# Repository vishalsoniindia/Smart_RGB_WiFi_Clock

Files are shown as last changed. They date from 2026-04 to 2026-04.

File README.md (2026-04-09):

# 🚀 ESP32 Easy Upload Tool

A simple way to erase and upload code to your ESP32 using a batch file.  

---

## 📌 How It Works
The included **`esp32_upload.bat`** file will:
- Automatically erase the ESP32 flash memory
- Upload your program
- Allow quick reprogramming for multiple devices

---

## 🔧 Steps to Upload Code

1. Open the folder and **double-click** `esp32_upload.bat`.
2. If Windows shows *"Windows Protected your PC"*, click:
   - **More Info**
   - **Run Anyway**
3. From the COM port list, **select the list number [NOT COM NUMBER]** where your ESP32 is connected.
4. Press **Enter** to continue.
5. Wait until you see:  
   ✅ **"Flash Complete"** at the end.
6. Press **any key** if you want to program another device.

---

## ⚠️ Notes
- Make sure your ESP32 is properly connected via USB.
- Run the script with administrator privileges if you face permission issues.

---

✨ That’s it! Your ESP32 should now be running the uploaded code.

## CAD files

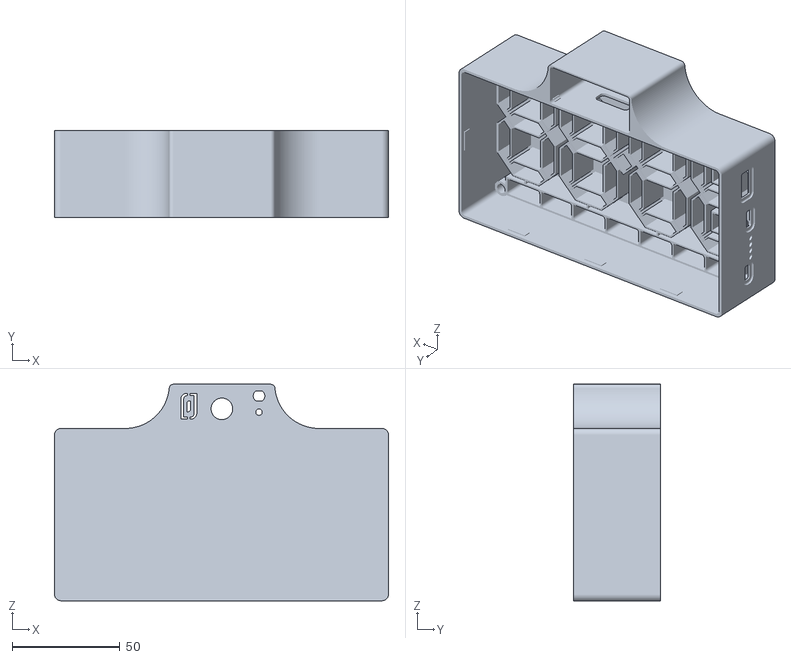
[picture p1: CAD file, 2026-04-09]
Mini_RGB_STL_Files/Main Case 1.stl
155.0 x 40.4 x 100.5

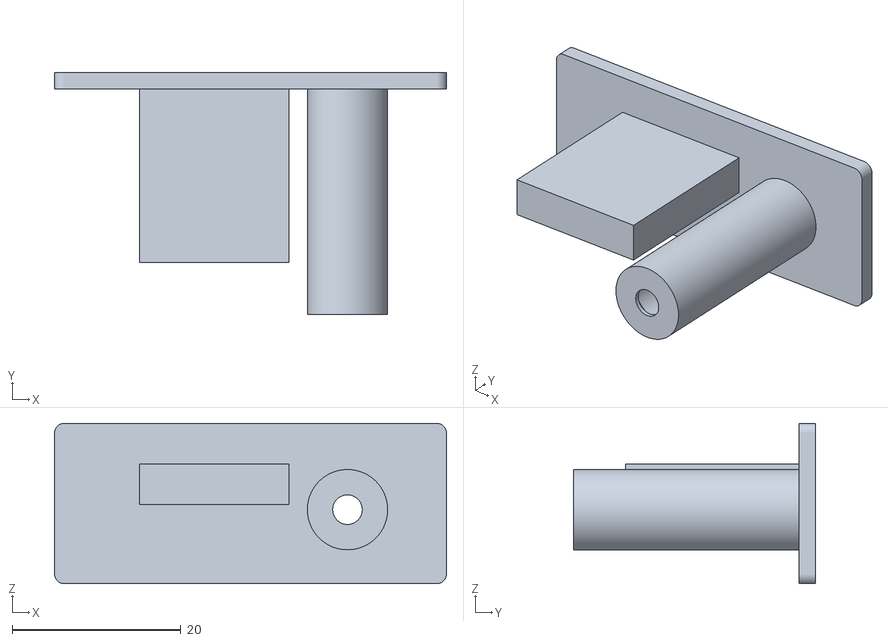
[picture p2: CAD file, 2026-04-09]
Mini_RGB_STL_Files/Sensor Cap 3.stl
46.4 x 28.7 x 19.0

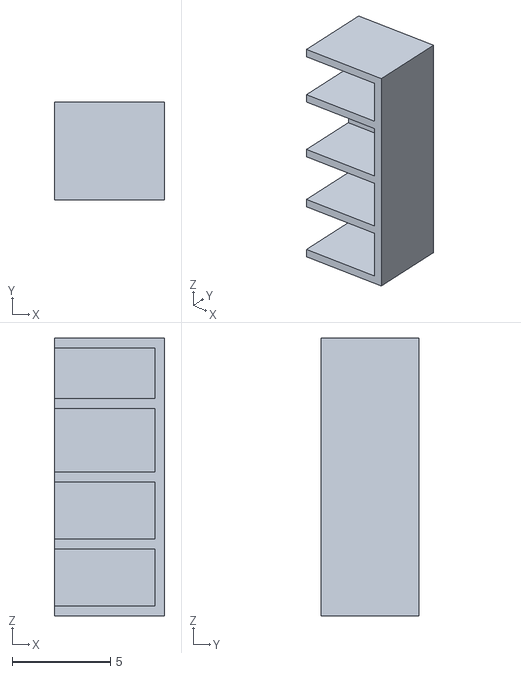
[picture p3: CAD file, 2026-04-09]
Mini_RGB_STL_Files/Fuel Guage sep 5.stl
5.60 x 5.00 x 14.1

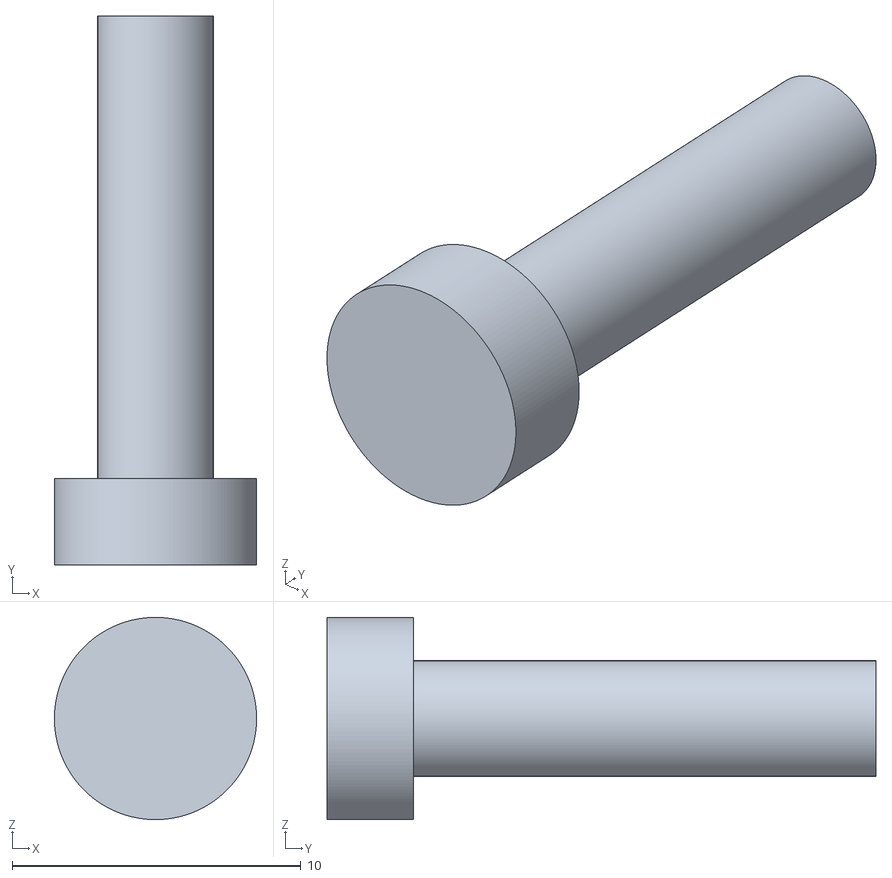
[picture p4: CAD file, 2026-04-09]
Mini_RGB_STL_Files/Key Lead 4.stl
7.00 x 19.0 x 7.00

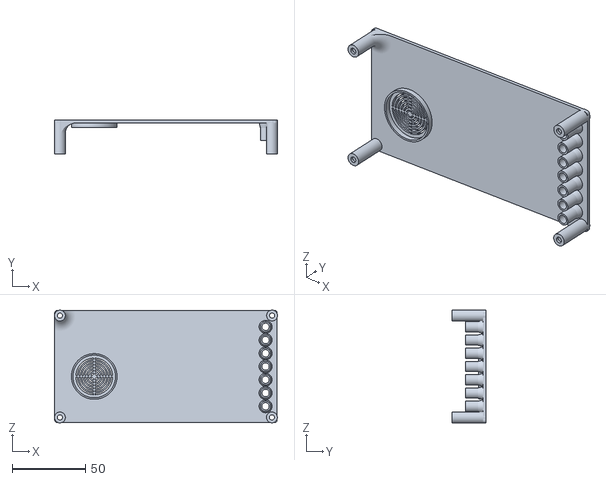
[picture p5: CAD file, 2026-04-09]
Mini_RGB_STL_Files/Back Cover 2.stl
151.8 x 23.0 x 76.8

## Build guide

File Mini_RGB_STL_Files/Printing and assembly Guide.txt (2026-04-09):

1)Threaded Brass Inserts
 M3x3mm  = 4 pc

2)Threaded Bolts
M3x8mm = 4 pc

3)Printing Guide
3.1 
We used Bambulab A1 printer Without AMS to print all the parts in PLA. 
We will keep front face of clock on build plate,
To Allow Light to Pass through PLA We are going to print 
first layer of MAIN CASE stl with LITHOPANE WHITE / WHITE PLA and put a pause, then change 
filament color to your choice for Remaining, we used Black for blocking Unnecessary lights .
all other parts can be Printed in your color of choice.

3.2
FUEL GUAGE stl part is required to stick on PCB where battery level led are placed making separation
for each led to avoid mixing of led light

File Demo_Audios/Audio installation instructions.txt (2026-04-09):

NOTE : Adding custom audio in jq6500 
You will need 6 Audios , Audio 1,2,3,4,5 corresponds to 5 Alarm and Audio 6 is for Theft Alarm. All are in mp3 format and all combined audio size should be below or up to 2000kb / 2 mb , most important is to enter audio name as 001 - 002 - 003 … where audio 1 is 001 and audio 2 is 002 and so on. Now you can Upload it in jQ6500 Module.

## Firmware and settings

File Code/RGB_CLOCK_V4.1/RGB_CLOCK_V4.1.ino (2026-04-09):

//parition scheme : Minimal SPIFFS

/*
* Auther : Vishal Soni (@electrodonut)
* ESP32 Board : V3.3.4
* FastLED : v3.10.3
* RTClib : v2.1.4
* DHT sensor Adafruit : v1.4.6
* JQ6500_Serial : (Link: https://github.com/sleemanj/JQ6500_Serial)
*/

/*++++++++++++++ Libraries ++++++++++++++++*/
#define FASTLED_ALLOW_INTERRUPTS 1
#define FASTLED_INTERRUPT_RETRY_COUNT 0

#include <Arduino.h>
#include <FastLED.h>
#include <Wire.h>
#include "RTClib.h"
#include <WiFi.h>
#include <ESPmDNS.h>
#include <WebServer.h>
#include <DNSServer.h>
#include <Preferences.h>
#include <ArduinoJson.h>
#include "DHT.h"
#include <JQ6500_Serial.h>
#include <Update.h>


#include "webpage.h"
#include "timezone.h"

/*++++++++++++++ Wifi ++++++++++++++++*/
String wifiSSID;
String wifiPassword;

WebServer server(80);
Preferences prefs;
Preferences wifiPrefs;
char mdnsHostname[32];

// Timezone handling
String tzString;  // Will hold POSIX timezone string

bool wifiConnected = false;
bool timeSynced = false;
unsigned long lastUpdateTime = 0;
bool apModeActive = false;
bool mdnsRunning = false;
bool serverRunning = false;


DNSServer dnsServer;
// const char* AP_PASSWORD = "12345678";  // ≥8 chars or set nullptr for open AP
const char *AP_PASSWORD = nullptr;
;  // ≥8 chars or set nullptr for open AP



/*++++++++++++++ Pin Declaration ++++++++++++++++*/
#define LED_PWR_RELAY 23
#define DATA_PIN 4
#define DHTPIN 18  // Digital pin connected to the DHT sensor
#define LDR 39
#define PIR 33
#define BUSY_AUDIO 25  //1 busy 0 free
#define UP_BUTTON 26
#define DOWN_BUTTON 27
#define OK_BUTTON 14
#define CONFIG_BUTTON 15

/*++++++++++++++ Display ++++++++++++++++*/
#define NUM_LEDS 73
CRGB leds[NUM_LEDS];         // Define the array of leds
int display_cycle_time = 3;  //seconds
unsigned long lastTimeDisplaySwitch = 0;
int Display_Value = 0;
#define MAX_DISPLAY_VALUES 3
String displayOnly;  // "all", "time", "temperature", "humidity"

/*++++++++++++++ Buttons ++++++++++++++++*/

const unsigned long debounceDelay = 50;  // ms

struct Button {
  uint8_t pin;
  bool lastStableState;
  bool lastReading;
  unsigned long lastDebounceTime;
  const char *name;
};

Button buttons[] = {
  { UP_BUTTON, LOW, LOW, 0, "UP" },
  { DOWN_BUTTON, LOW, LOW, 0, "DOWN" },
  { OK_BUTTON, LOW, LOW, 0, "OK" },
  { CONFIG_BUTTON, LOW, LOW, 0, "CONFIG" }
};

const int buttonCount = sizeof(buttons) / sizeof(buttons[0]);

/*++++++++++++++ Sound define ++++++++++++++++*/
#define Alarm1Sound 1
#define Alarm2Sound 2
#define Alarm3Sound 3
#define Alarm4Sound 4
#define Alarm5Sound 5
#define TheftAlarmSound 6
uint8_t alarm_volume = 30;

/*++++++++++++++ Alarm System ++++++++++++++++*/
// Alarm structure for 5 alarms
struct Alarm {
  bool enabled;
  int hour;
  int minute;
  int sound_num;
  unsigned long snooz_minute;
  int back_up_h;
  int back_up_m;
};

#define ALARM_COUNT 5

Alarm alarms[ALARM_COUNT] = {
  //true/false(enable/disale) , hour , minute, sound number, snooz minute, backup hour and backup minte?
  { false, 7, 0, Alarm1Sound, 1, 7, 0 },    // Alarm 1 - default 7:00 AM snooze 1 minute
  { false, 8, 0, Alarm2Sound, 10, 8, 0 },   // Alarm 2 - default 8:00 AM snooze 10 minute
  { false, 9, 0, Alarm3Sound, 5, 9, 0 },    // Alarm 3 - default 9:00 AM snooze 5 minute
  { false, 10, 0, Alarm4Sound, 0, 10, 0 },  // Alarm 4 - default 10:00 AM
  { false, 13, 0, Alarm5Sound, 0, 13, 0 }   // Alarm 5 - default 1:00 PM
};

bool alarm_is_active = 0;
bool is_snooz_pressed = 0;
int current_active_alarm = 0;

/*++++++++++++++ PIR ++++++++++++++++*/
bool first_time_on_before_pir = 0;
bool is_pir_on = 1;
bool turn_on_relay = 0;
int time_out_for_led_off = 1;  // 1 minute on
// int time_out_for_led_off = 1000 * 5 * 1;  // 1 minute on
unsigned long lastTimePirOn = 0;
JQ6500_Serial mp3(Serial2);

bool is_theft_on = 0;
int theftSoundTimeout;  // seconds
bool theftTimingEnabled;
struct TheftTime {
  uint8_t hour;
  uint8_t minute;
} theftStartTime, theftEndTime;
bool theftTimingInRange = 0;  //if in range turn it 1
bool Theft_active = 0;        //whill 1 if theft audio playing

/*++++++++++++++ LDR ++++++++++++++++*/
bool autoBrightness = 1;
int minRawValue = 4095;  // Expected in complete darkness
int maxRawValue = 1425;  // Expected in bright light
int minLedBrightness = 10;
int maxLedBrightness = 255;
int rawValue = 0;
int brightness;
// int lightLevel = 0;

/*++++++++++++++ DHT 11 ++++++++++++++++*/
bool is_temp_in_f = 0;
#define DHTTYPE DHT11
DHT dht(DHTPIN, DHTTYPE);
float humidity = 0;
float temperature = 0;

/*++++++++++++++ LEds ++++++++++++++++*/

// Define segments as reusable objects
CRGBSet hour_1(leds + 0, 14);   // First hour digit (LEDs 0-13, 14 LEDs total)
CRGBSet hour_2(leds + 14, 14);  // Second hour digit (LEDs 14-27, 14 LEDs)
CRGBSet sep_dot(leds + 28, 1);  // Separator dot (LED 28 only, 1 LED)
CRGBSet min_1(leds + 29, 14);   // First minute digit (LEDs 29-42, 14 LEDs)
CRGBSet min_2(leds + 43, 14);   // Second minute digit (LEDs 43-56, 14 LEDs)
CRGBSet sun(leds + 57, 2);
CRGBSet sat(leds + 59, 2);
CRGBSet fri(leds + 61, 2);
CRGBSet thu(leds + 63, 2);
CRGBSet wed(leds + 65, 2);
CRGBSet tue(leds + 67, 2);
CRGBSet mon(leds + 69, 2);
CRGBSet al(leds + 71, 1);
CRGBSet pm(leds + 72, 1);

unsigned long currentMillis = 0;
unsigned long lastPrintTime = 0;

// Animation variables
uint8_t gHue = 0;  // Global hue for rainbow

/*++++++++++++++ Time ++++++++++++++++*/
RTC_DS3231 rtc;
uint8_t hours = 2;
uint8_t minutes = 2;
uint8_t seconds = 0;

uint8_t date = 5;
uint8_t month = 10;
int year = 2001;
uint8_t weekday = 0;
uint8_t lastweekday = 255;

char daysOfWeek[7][12] = { "Sunday", "Monday", "Tuesday", "Wednesday", "Thursday", "Friday", "Saturday" };

bool enable_24_hour_mode = 0;  //make 1 to enable 24 hour mode
bool is_pm = 0;                //will 1 if pm
String timezone;
String timeMode;  // "12" or "24"

CRGB weekday_bg_color = CRGB::White;
CRGB weekday_selected_color = CRGB::Magenta;

/*++++++++++++++ Colors Solid ++++++++++++++++*/

String colorMode;
String solidColor;
String effect;

enum color_mode {
  SOLID,
  EFFECT
};

enum color_mode Color_Mode = EFFECT;

enum color_of_time {
  RED,  // Basic colors
  GREEN,
  BLUE,
  WHITE,
  BLACK,   // Off
  YELLOW,  // Secondary colors
  CYAN,
  MAGENTA,
  ORANGE,  // Tertiary colors
  PURPLE,
  PINK,
  TEAL,
  LIME,
  AMBER,  // Warm colors
  GOLD,
  CORAL,
  LAVENDER,  // Pastels
  SKYBLUE,
  FORESTGREEN,
  MAROON,
  OLIVE,
  NAVY,
  INDIGO
};

enum color_of_time current_color = MAROON;

/*++++++++++++++ effects of time ++++++++++++++++*/

enum effect_of_time {
  RAINBOW_1,  // slow rainbow
  RAINBOW_2,
  RAINBOW_3
};

enum effect_of_time current_effect = RAINBOW_2;

/* ---- Theme ---- */
bool lightTheme;

// ===================== declaration =====================
long getUtcOffsetSeconds(const String &tz);

// ===================== Setup() =====================

void setup() {
  Serial.begin(115200);
  Serial.println("========================== Beginning of Code ============================");
  loadPreferences();
  loadWiFiCredentials();

  WiFi.begin(wifiSSID.c_str(), wifiPassword.c_str());
  update_hostname();

  // FastLED.addLeds<WS2812B, DATA_PIN, GRB>(leds, NUM_LEDS);  // GRB ordering is typical
  FastLED.addLeds<WS2812B, DATA_PIN, GRB>(leds, NUM_LEDS).setCorrection(TypicalLEDStrip);

  Wire.begin();  // Initialize I2C with default pins (21-SDA, 22-SCL)

  // Initialize RTC
  if (!rtc.begin()) {
    Serial.println("Couldn't find RTC!");
    Serial.flush();
    while (1) delay(10);
  }

  dht.begin();

  Serial2.begin(9600, SERIAL_8N1, 16, 17);
  mp3.reset();
  mp3.setVolume(alarm_volume);
  mp3.setLoopMode(MP3_LOOP_NONE);

  pinMode(BUSY_AUDIO, INPUT);
  pinMode(LDR, INPUT);
  pinMode(PIR, INPUT);
  pinMode(LED_PWR_RELAY, OUTPUT);
  digitalWrite(LED_PWR_RELAY, HIGH);
  turn_on_relay = 1;

  // server_start();

  // test alarm
  // DateTime now = rtc.now();
  // hours = now.hour();
  // minutes = now.minute();
  // seconds = now.second();
  // set_alarm(1, true, hours, minutes + 1, Alarm1Sound, 1);  //alarm number(1-5), enable(true-false), hour, minute, sound, snooze minute
}

// ===================== Loop() =====================

void loop() {
  server.handleClient();
  if (apModeActive) {
    dnsServer.processNextRequest();
  }
  currentMillis = millis();
  button_handler();
  PIR_handle();
  updateTime();
  handle_alarm();
  PrintDebug();
  WifiHandle();
  UpdateDHT();

  // EVERY_N_MILLISECONDS(33) {  // ~30 FPS

  if (turn_on_relay) {
    autoBrightness_handle();
    // FastLED.setBrightness(255);
    display_weekday();
    Alarm_led_handle();

    if ((currentMillis - lastTimeDisplaySwitch > (display_cycle_time * 1000)) && displayOnly == "all") {
      lastTimeDisplaySwitch = currentMillis;
      Display_Value = (Display_Value + 1) % MAX_DISPLAY_VALUES;
      clearAllSegments_NoWeek();
    }

    if (Color_Mode == SOLID) {
      if (Display_Value == 0) {
        displayTime((uint8_t)current_color, Color_Mode);
      } else if (Display_Value == 1) {
        displayHumidity((uint8_t)current_color, Color_Mode);
      } else if (Display_Value == 2) {
        displayTemperature((uint8_t)current_color, Color_Mode);
      }
    } else {
      if (Display_Value == 0) {
        displayTime((uint8_t)current_effect, Color_Mode);
      } else if (Display_Value == 1) {
        displayHumidity((uint8_t)current_effect, Color_Mode);
      } else if (Display_Value == 2) {
        displayTemperature((uint8_t)current_effect, Color_Mode);
      }
      // Update animation based on effect speed
      if (current_effect == RAINBOW_1) {
        gHue++;            // Update hue for animation
        FastLED.delay(5);  // Fast animation
      } else if (current_effect == RAINBOW_2) {
        gHue++;             // Update hue for animation
        FastLED.delay(15);  // Medium animation
      } else if (current_effect == RAINBOW_3) {
        gHue++;             // Update hue for animation
        FastLED.delay(30);  // Slow animation
      }
    }

    FastLED.show();
  }
  // }
}

// ===================== Button Handler =====================
void button_handler() {
  for (int i = 0; i < buttonCount; i++) {
    bool reading = digitalRead(buttons[i].pin);

    // If state changed, reset debounce timer
    if (reading != buttons[i].lastReading) {
      buttons[i].lastDebounceTime = millis();
    }

    // If debounce time passed, accept new state
    if ((millis() - buttons[i].lastDebounceTime) > debounceDelay) {
      if (reading != buttons[i].lastStableState) {
        buttons[i].lastStableState = reading;

        // Print only on press (HIGH)
        if (reading == HIGH) {
          Serial.print(buttons[i].name);
          Serial.println(" button pressed");

          switch (buttons[i].pin) {
            case UP_BUTTON:
              break;
            case DOWN_BUTTON:
              break;
            case OK_BUTTON:
              if (alarm_is_active) {
                is_snooz_pressed = 1;
              }
              break;
            case CONFIG_BUTTON:
              startAPMode();
              break;
            default:
              break;
          }
        }
      }
    }

    buttons[i].lastReading = reading;
  }
}

// ===================== Audio =====================
void stop_audio() {
  mp3.reset();
  mp3.setVolume(alarm_volume);
}

// ===================== Set Alarm =====================

void handle_alarm() {
  for (int i = 0; i < ALARM_COUNT; i++) {
    if (alarms[i].enabled) {
      if (alarms[i].hour == hours && alarms[i].minute == minutes && seconds == 0) {

        current_active_alarm = i;
        Serial.println("============================================");
        Serial.print("Alarm Started: ");
        Serial.println(current_active_alarm + 1);
        Serial.println("============================================");

        if (alarms[i].hour == alarms[i].back_up_h && alarms[i].minute == alarms[i].back_up_m) {
          reset_alarm_to_defult();  //this well remove any snooze times
        }

        if (is_pir_on && !turn_on_relay) {
          TurnOnDisplay();
          turn_on_relay = 1;
        }
        if (digitalRead(BUSY_AUDIO)) {
          stop_audio();
        }
        mp3.setLoopMode(MP3_LOOP_ONE_STOP);
        mp3.playFileByIndexNumber(alarms[i].sound_num);
        alarm_is_active = 1;
        Theft_active = 0;  //stop theft if alarm start
      }
    }
  }

  if (alarm_is_active) {

    //no snooze pressed & completed
    if (!digitalRead(BUSY_AUDIO)) {
      Serial.println("============================================");
      Serial.print("Alarm Stopped: ");
      Serial.println(current_active_alarm + 1);
      Serial.println("============================================");
      alarm_is_active = 0;
      if (is_pir_on && turn_on_relay) {
        turn_on_relay = 0;
        TurnOffDisplay();
      }
      reset_alarm_to_defult();
    }

    //snooze pressed
    if (is_snooz_pressed) {
      Serial.println("============================================");
      Serial.print("Alarm Snooze: ");
      Serial.println(current_active_alarm + 1);
      Serial.println("============================================");
      stop_audio();
      is_snooz_pressed = 0;
      alarm_is_active = 0;
      addMinutes(alarms[current_active_alarm].hour, alarms[current_active_alarm].minute, alarms[current_active_alarm].snooz_minute);
      if (is_pir_on) {
        turn_on_relay = 0;
        TurnOffDisplay();
      }
    }
  }
}

void reset_alarm_to_defult() {
  for (int i = 0; i < 5; i++) {
    alarms[i].hour = alarms[i].back_up_h;
    alarms[i].minute = alarms[i].back_up_m;
  }
}

void addMinutes(int &hours, int &minutes, int minutesToAdd) {
  // Convert everything to total minutes
  int totalMinutes = hours * 60 + minutes + minutesToAdd;

  // Handle rollover (24-hour format)
  totalMinutes = totalMinutes % (24 * 60);

  // Convert back to hours and minutes
  hours = totalMinutes / 60;
  minutes = totalMinutes % 60;
}

void set_alarm(uint8_t alarm_num, bool alarm_state, uint8_t alarm_hour, uint8_t alarm_minute, uint8_t alarm_sound, int snooze_minute) {  //alarm number(1-5), enable(true-false), hour, minute, sound, snooze minute
  alarm_num = alarm_num - 1;                                                                                                             //convert to array
  alarms[alarm_num].enabled = alarm_state;
  alarms[alarm_num].hour = alarm_hour;
  alarms[alarm_num].minute = alarm_minute;
  alarms[alarm_num].sound_num = alarm_sound;
  alarms[alarm_num].snooz_minute = snooze_minute;
  alarms[alarm_num].back_up_h = alarm_hour;
  alarms[alarm_num].back_up_m = alarm_minute;
}

void toggle_alarm(uint8_t alarm_num, bool alarm_state) {
  alarm_num = alarm_num - 1;  //convert to array
  alarms[alarm_num].enabled = alarm_state;
}

// ===================== Turn On Display =====================

void TurnOnDisplay() {
  digitalWrite(LED_PWR_RELAY, HIGH);
}

void TurnOffDisplay() {
  digitalWrite(LED_PWR_RELAY, LOW);
}

// ===================== PIR =====================

void PIR_handle() {
  if (theftTimingEnabled) {
    theftTimingInRange = is_time_between(hours, minutes, theftStartTime.hour, theftStartTime.minute, theftEndTime.hour, theftEndTime.minute);
  } else {
    theftTimingInRange = 1;
  }

  if (Theft_active && !digitalRead(BUSY_AUDIO)) {
    mp3.setLoopMode(MP3_LOOP_ONE);
    mp3.playFileByIndexNumber(TheftAlarmSound);
  }

  if (is_pir_on) {
    //first time on
    if (turn_on_relay && (currentMillis - lastTimePirOn) > (10 * 1000) && !Theft_active && !first_time_on_before_pir) {
      turn_on_relay = 0;
      TurnOffDisplay();
      first_time_on_before_pir = 1;
    }

    if (turn_on_relay && (currentMillis - lastTimePirOn) > (time_out_for_led_off * 1000 * 60) && !Theft_active) {
      if (is_theft_on && !alarm_is_active) {
        stop_audio();
      }
      turn_on_relay = 0;
      TurnOffDisplay();
    }

    //for theft
    if ((currentMillis - lastTimePirOn) > (theftSoundTimeout * 1000) && is_theft_on && Theft_active && !alarm_is_active) {
      stop_audio();
      Theft_active = 0;
      turn_on_relay = 0;
      TurnOffDisplay();
    }

    if (digitalRead(PIR) == HIGH && !turn_on_relay && !alarm_is_active) {
      if (is_theft_on && !alarm_is_active && theftTimingInRange) {
        Theft_active = 1;
      }

      TurnOnDisplay();
      turn_on_relay = 1;
      lastTimePirOn = currentMillis;
    }

    // if (turn_on_relay && is_theft_on && !digitalRead(BUSY_AUDIO)) {
    //   mp3.playFileByIndexNumber(TheftAlarmSound);
    // }

  } else {
    TurnOnDisplay();
    turn_on_relay = 1;

    if (digitalRead(PIR) == HIGH && !alarm_is_active && is_theft_on && theftTimingInRange) {
      Theft_active = 1;
      lastTimePirOn = currentMillis;
    }

    if ((currentMillis - lastTimePirOn) > (theftSoundTimeout * 1000) && is_theft_on && Theft_active && !alarm_is_active) {
      stop_audio();
      Theft_active = 0;
    }
  }
}

void checkRangeOfTheftTime() {
  bool theftTimingEnabled;
  struct TheftTime {
    uint8_t hour;
    uint8_t minute;
  } theftStartTime, theftEndTime;
  bool theftTimingInRange = 0;  //if in range turn it 1

  if (theftTimingEnabled) {
    theftTimingInRange = 0;
    if (theftStartTime.hour) {
    }
  } else {
    theftTimingInRange = 1;
  }
}

// Function to check if current time is between start and end times
int is_time_between(int current_hour, int current_minute,
                    int start_hour, int start_minute,
                    int end_hour, int end_minute) {

  // Convert all times to minutes since midnight
  int current_total = current_hour * 60 + current_minute;
  int start_total = start_hour * 60 + start_minute;
  int end_total = end_hour * 60 + end_minute;

  if (start_total <= end_total) {
    // Normal same-day case
    if (start_total <= current_total && current_total <= end_total) {
      return 1;
    }
  } else {
    // Next-day case (end time is on next day)
    if (current_total >= start_total || current_total <= end_total) {
      return 1;
    }
  }
  return 0;
}

// ===================== LDR =====================

float smoothedLightLevel = 0.0;  // Initial value
const float alpha = 0.2;         // Smoothing factor (0.1-0.3). Lower = smoother, slower response.
unsigned long lastLDRRead = 0;
const unsigned long LDR_READ_INTERVAL = 100;  // Read every 100ms

// Modify autoBrightness() function
void autoBrightness_handle() {
  if (autoBrightness) {
    if (currentMillis - lastLDRRead >= LDR_READ_INTERVAL) {
      lastLDRRead = currentMillis;
      rawValue = analogRead(LDR);

      // The LDR reading is INVERTED: high value = dark, low value = bright.
      int newLightLevel = map(rawValue, minRawValue, maxRawValue, minLedBrightness, maxLedBrightness);
      newLightLevel = constrain(newLightLevel, minLedBrightness, maxLedBrightness);

      // Apply Exponential Moving Average Filter
      smoothedLightLevel = (alpha * newLightLevel) + ((1 - alpha) * smoothedLightLevel);

      // Apply the smoothed brightness
      FastLED.setBrightness((int)smoothedLightLevel);
    }
  } else {
    int newLightLevel = map(brightness, 0, 100, minLedBrightness, maxLedBrightness);
    FastLED.setBrightness(newLightLevel);
  }
}


// ===================== Update DHT =====================
void UpdateDHT() {
  humidity = dht.readHumidity();

  if (!is_temp_in_f) {
    // Read temperature as Celsius (the default)
    temperature = dht.readTemperature();
  } else {
    // Read temperature as Fahrenheit (isFahrenheit = true)
    temperature = dht.readTemperature(true);
  }

  if (isnan(humidity) || isnan(temperature)) {
    Serial.println(F("Failed to read from DHT sensor!"));
    return;
  }
}

// ===================== DIGIT PATTERNS =====================
// Each digit pattern controls 14 LEDs (like two 7-segment digits)
// 1 = LED ON, 0 = LED OFF
const bool digitPattern[13][14] = {
  // Digit 0
  { 1, 1, 1, 1, 1, 1, 0, 0, 1, 1, 1, 1, 1, 1 },
  // Digit 1
  { 0, 0, 0, 0, 1, 1, 0, 0, 0, 0, 0, 0, 1, 1 },
  // Digit 2
  { 0, 0, 1, 1, 1, 1, 1, 1, 1, 1, 1, 1, 0, 0 },
  // Digit 3
  { 0, 0, 1, 1, 1, 1, 1, 1, 0, 0, 1, 1, 1, 1 },
  // Digit 4
  { 1, 1, 0, 0, 1, 1, 1, 1, 0, 0, 0, 0, 1, 1 },
  // Digit 5
  { 1, 1, 1, 1, 0, 0, 1, 1, 0, 0, 1, 1, 1, 1 },
  // Digit 6
  { 1, 1, 1, 1, 0, 0, 1, 1, 1, 1, 1, 1, 1, 1 },
  // Digit 7
  { 0, 0, 1, 1, 1, 1, 0, 0, 0, 0, 0, 0, 1, 1 },
  // Digit 8
  { 1, 1, 1, 1, 1, 1, 1, 1, 1, 1, 1, 1, 1, 1 },
  // Digit 9
  { 1, 1, 1, 1, 1, 1, 1, 1, 0, 0, 1, 1, 1, 1 },
  // Digit 10 /H
  { 1, 1, 0, 0, 1, 1, 1, 1, 1, 1, 0, 0, 1, 1 },
  // Digit 11 /F
  { 1, 1, 1, 1, 0, 0, 1, 1, 1, 1, 0, 0, 0, 0 },
  // Digit 12 /C
  { 1, 1, 1, 1, 0, 0, 0, 0, 1, 1, 1, 1, 0, 0 },
};

// ===================== CORE FUNCTIONS =====================
void Alarm_led_handle() {
  al[0] = CRGB::Black;
  for (int i = 0; i < 5; i++) {
    if (alarms[i].enabled) {
      al[0] = CRGB::Red;
    }
  }
}

void display_weekday() {
  if (lastweekday != weekday) {
    // Serial.print("last week:");
    // Serial.print(lastweekday);
    // Serial.print(" ");
    // Serial.print("week:");
    // Serial.println(weekday);
    lastweekday = weekday;
    highlightDay(weekday_bg_color, weekday_selected_color, weekday);
  }
}
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

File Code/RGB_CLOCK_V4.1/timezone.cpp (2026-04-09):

// timezones.cpp
#include "timezone.h"

// Define the actual array here
const TimezoneEntry timezoneDatabase[] PROGMEM = {
    {"Africa/Abidjan", "GMT0"},
    {"Africa/Accra", "GMT0"},
    {"Africa/Addis_Ababa", "EAT-3"},
    {"Africa/Algiers", "CET-1"},
    {"Africa/Asmara", "EAT-3"},
    {"Africa/Bamako", "GMT0"},
    {"Africa/Bangui", "WAT-1"},
    {"Africa/Banjul", "GMT0"},
    {"Africa/Bissau", "GMT0"},
    {"Africa/Blantyre", "CAT-2"},
    {"Africa/Brazzaville", "WAT-1"},
    {"Africa/Bujumbura", "CAT-2"},
    {"Africa/Cairo", "EET-2EEST,M4.5.5/0,M10.5.4/24"},
    {"Africa/Casablanca", "<+01>-1"},
    {"Africa/Ceuta", "CET-1CEST,M3.5.0,M10.5.0/3"},
    {"Africa/Conakry", "GMT0"},
    {"Africa/Dakar", "GMT0"},
    {"Africa/Dar_es_Salaam", "EAT-3"},
    {"Africa/Djibouti", "EAT-3"},
    {"Africa/Douala", "WAT-1"},
    {"Africa/El_Aaiun", "<+01>-1"},
    {"Africa/Freetown", "GMT0"},
    {"Africa/Gaborone", "CAT-2"},
    {"Africa/Harare", "CAT-2"},
    {"Africa/Johannesburg", "SAST-2"},
    {"Africa/Juba", "CAT-2"},
    {"Africa/Kampala", "EAT-3"},
    {"Africa/Khartoum", "CAT-2"},
    {"Africa/Kigali", "CAT-2"},
    {"Africa/Kinshasa", "WAT-1"},
    {"Africa/Lagos", "WAT-1"},
    {"Africa/Libreville", "WAT-1"},
    {"Africa/Lome", "GMT0"},
    {"Africa/Luanda", "WAT-1"},
    {"Africa/Lubumbashi", "CAT-2"},
    {"Africa/Lusaka", "CAT-2"},
    {"Africa/Malabo", "WAT-1"},
    {"Africa/Maputo", "CAT-2"},
    {"Africa/Maseru", "SAST-2"},
    {"Africa/Mbabane", "SAST-2"},
    {"Africa/Mogadishu", "EAT-3"},
    {"Africa/Monrovia", "GMT0"},
    {"Africa/Nairobi", "EAT-3"},
    {"Africa/Ndjamena", "WAT-1"},
    {"Africa/Niamey", "WAT-1"},
    {"Africa/Nouakchott", "GMT0"},
    {"Africa/Ouagadougou", "GMT0"},
    {"Africa/Porto-Novo", "WAT-1"},
    {"Africa/Sao_Tome", "GMT0"},
    {"Africa/Tripoli", "EET-2"},
    {"Africa/Tunis", "CET-1"},
    {"Africa/Windhoek", "CAT-2"},
    {"America/Adak", "HST10HDT,M3.2.0,M11.1.0"},
    {"America/Anchorage", "AKST9AKDT,M3.2.0,M11.1.0"},
    {"America/Anguilla", "AST4"},
    {"America/Antigua", "AST4"},
    {"America/Araguaina", "<-03>3"},
    {"America/Argentina/Buenos_Aires", "<-03>3"},
    {"America/Argentina/Catamarca", "<-03>3"},
    {"America/Argentina/Cordoba", "<-03>3"},
    {"America/Argentina/Jujuy", "<-03>3"},
    {"America/Argentina/La_Rioja", "<-03>3"},
    {"America/Argentina/Mendoza", "<-03>3"},
    {"America/Argentina/Rio_Gallegos", "<-03>3"},
    {"America/Argentina/Salta", "<-03>3"},
    {"America/Argentina/San_Juan", "<-03>3"},
    {"America/Argentina/San_Luis", "<-03>3"},
    {"America/Argentina/Tucuman", "<-03>3"},
    {"America/Argentina/Ushuaia", "<-03>3"},
    {"America/Aruba", "AST4"},
    {"America/Asuncion", "<-03>3"},
    {"America/Atikokan", "EST5"},
    {"America/Bahia", "<-03>3"},
    {"America/Bahia_Banderas", "CST6"},
    {"America/Barbados", "AST4"},
    {"America/Belem", "<-03>3"},
    {"America/Belize", "CST6"},
    {"America/Blanc-Sablon", "AST4"},
    {"America/Boa_Vista", "<-04>4"},
    {"America/Bogota", "<-05>5"},
    {"America/Boise", "MST7MDT,M3.2.0,M11.1.0"},
    {"America/Cambridge_Bay", "MST7MDT,M3.2.0,M11.1.0"},
    {"America/Campo_Grande", "<-04>4"},
    {"America/Cancun", "EST5"},
    {"America/Caracas", "<-04>4"},
    {"America/Cayenne", "<-03>3"},
    {"America/Cayman", "EST5"},
    {"America/Chicago", "CST6CDT,M3.2.0,M11.1.0"},
    {"America/Chihuahua", "CST6"},
    {"America/Costa_Rica", "CST6"},
    {"America/Creston", "MST7"},
    {"America/Cuiaba", "<-04>4"},
    {"America/Curacao", "AST4"},
    {"America/Danmarkshavn", "GMT0"},
    {"America/Dawson", "MST7"},
    {"America/Dawson_Creek", "MST7"},
    {"America/Denver", "MST7MDT,M3.2.0,M11.1.0"},
    {"America/Detroit", "EST5EDT,M3.2.0,M11.1.0"},
    {"America/Dominica", "AST4"},
    {"America/Edmonton", "MST7MDT,M3.2.0,M11.1.0"},
    {"America/Eirunepe", "<-05>5"},
    {"America/El_Salvador", "CST6"},
    {"America/Fort_Nelson", "MST7"},
    {"America/Fortaleza", "<-03>3"},
    {"America/Glace_Bay", "AST4ADT,M3.2.0,M11.1.0"},
    {"America/Godthab", "<-02>2<-01>,M3.5.0/-1,M10.5.0/0"},
    {"America/Goose_Bay", "AST4ADT,M3.2.0,M11.1.0"},
    {"America/Grand_Turk", "EST5EDT,M3.2.0,M11.1.0"},
    {"America/Grenada", "AST4"},
    {"America/Guadeloupe", "AST4"},
    {"America/Guatemala", "CST6"},
    {"America/Guayaquil", "<-05>5"},
    {"America/Guyana", "<-04>4"},
    {"America/Halifax", "AST4ADT,M3.2.0,M11.1.0"},
    {"America/Havana", "CST5CDT,M3.2.0/0,M11.1.0/1"},
    {"America/Hermosillo", "MST7"},
    {"America/Indiana/Indianapolis", "EST5EDT,M3.2.0,M11.1.0"},
    {"America/Indiana/Knox", "CST6CDT,M3.2.0,M11.1.0"},
    {"America/Indiana/Marengo", "EST5EDT,M3.2.0,M11.1.0"},
    {"America/Indiana/Petersburg", "EST5EDT,M3.2.0,M11.1.0"},
    {"America/Indiana/Tell_City", "CST6CDT,M3.2.0,M11.1.0"},
    {"America/Indiana/Vevay", "EST5EDT,M3.2.0,M11.1.0"},
    {"America/Indiana/Vincennes", "EST5EDT,M3.2.0,M11.1.0"},
    {"America/Indiana/Winamac", "EST5EDT,M3.2.0,M11.1.0"},
    {"America/Inuvik", "MST7MDT,M3.2.0,M11.1.0"},
    {"America/Iqaluit", "EST5EDT,M3.2.0,M11.1.0"},
    {"America/Jamaica", "EST5"},
    {"America/Juneau", "AKST9AKDT,M3.2.0,M11.1.0"},
    {"America/Kentucky/Louisville", "EST5EDT,M3.2.0,M11.1.0"},
    {"America/Kentucky/Monticello", "EST5EDT,M3.2.0,M11.1.0"},
    {"America/Kralendijk", "AST4"},
    {"America/La_Paz", "<-04>4"},
    {"America/Lima", "<-05>5"},
    {"America/Los_Angeles", "PST8PDT,M3.2.0,M11.1.0"},
    {"America/Lower_Princes", "AST4"},
    {"America/Maceio", "<-03>3"},
    {"America/Managua", "CST6"},
    {"America/Manaus", "<-04>4"},
    {"America/Marigot", "AST4"},
    {"America/Martinique", "AST4"},
    {"America/Matamoros", "CST6CDT,M3.2.0,M11.1.0"},
    {"America/Mazatlan", "MST7"},
    {"America/Menominee", "CST6CDT,M3.2.0,M11.1.0"},
    {"America/Merida", "CST6"},
    {"America/Metlakatla", "AKST9AKDT,M3.2.0,M11.1.0"},
    {"America/Mexico_City", "CST6"},
    {"America/Miquelon", "<-03>3<-02>,M3.2.0,M11.1.0"},
    {"America/Moncton", "AST4ADT,M3.2.0,M11.1.0"},
    {"America/Monterrey", "CST6"},
    {"America/Montevideo", "<-03>3"},
    {"America/Montreal", "EST5EDT,M3.2.0,M11.1.0"},
    {"America/Montserrat", "AST4"},
    {"America/Nassau", "EST5EDT,M3.2.0,M11.1.0"},
    {"America/New_York", "EST5EDT,M3.2.0,M11.1.0"},
    {"America/Nipigon", "EST5EDT,M3.2.0,M11.1.0"},
    {"America/Nome", "AKST9AKDT,M3.2.0,M11.1.0"},
    {"America/Noronha", "<-02>2"},
    {"America/North_Dakota/Beulah", "CST6CDT,M3.2.0,M11.1.0"},
    {"America/North_Dakota/Center", "CST6CDT,M3.2.0,M11.1.0"},
    {"America/North_Dakota/New_Salem", "CST6CDT,M3.2.0,M11.1.0"},
    {"America/Nuuk", "<-02>2<-01>,M3.5.0/-1,M10.5.0/0"},
    {"America/Ojinaga", "CST6CDT,M3.2.0,M11.1.0"},
    {"America/Panama", "EST5"},
    {"America/Pangnirtung", "EST5EDT,M3.2.0,M11.1.0"},
    {"America/Paramaribo", "<-03>3"},
    {"America/Phoenix", "MST7"},
    {"America/Port-au-Prince", "EST5EDT,M3.2.0,M11.1.0"},
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

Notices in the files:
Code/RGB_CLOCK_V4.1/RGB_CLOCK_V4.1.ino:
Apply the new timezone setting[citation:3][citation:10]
